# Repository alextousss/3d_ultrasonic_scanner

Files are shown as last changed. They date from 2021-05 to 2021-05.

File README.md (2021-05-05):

pic of a room 3d scanned with ultrasounds
### An Ultrasonic 3D Scanner

Detailed build log and infos [on my website](http://alextoussaint.com/2021-04-28_How-I-built-an-ultrasonic-3d-scanner.html) 

If you're looking for instructions detailed enough to build it for yourself, just add an Issue and I'll do it.
I also haven't had the time to make the code human-readable. Though, it's still understandable.

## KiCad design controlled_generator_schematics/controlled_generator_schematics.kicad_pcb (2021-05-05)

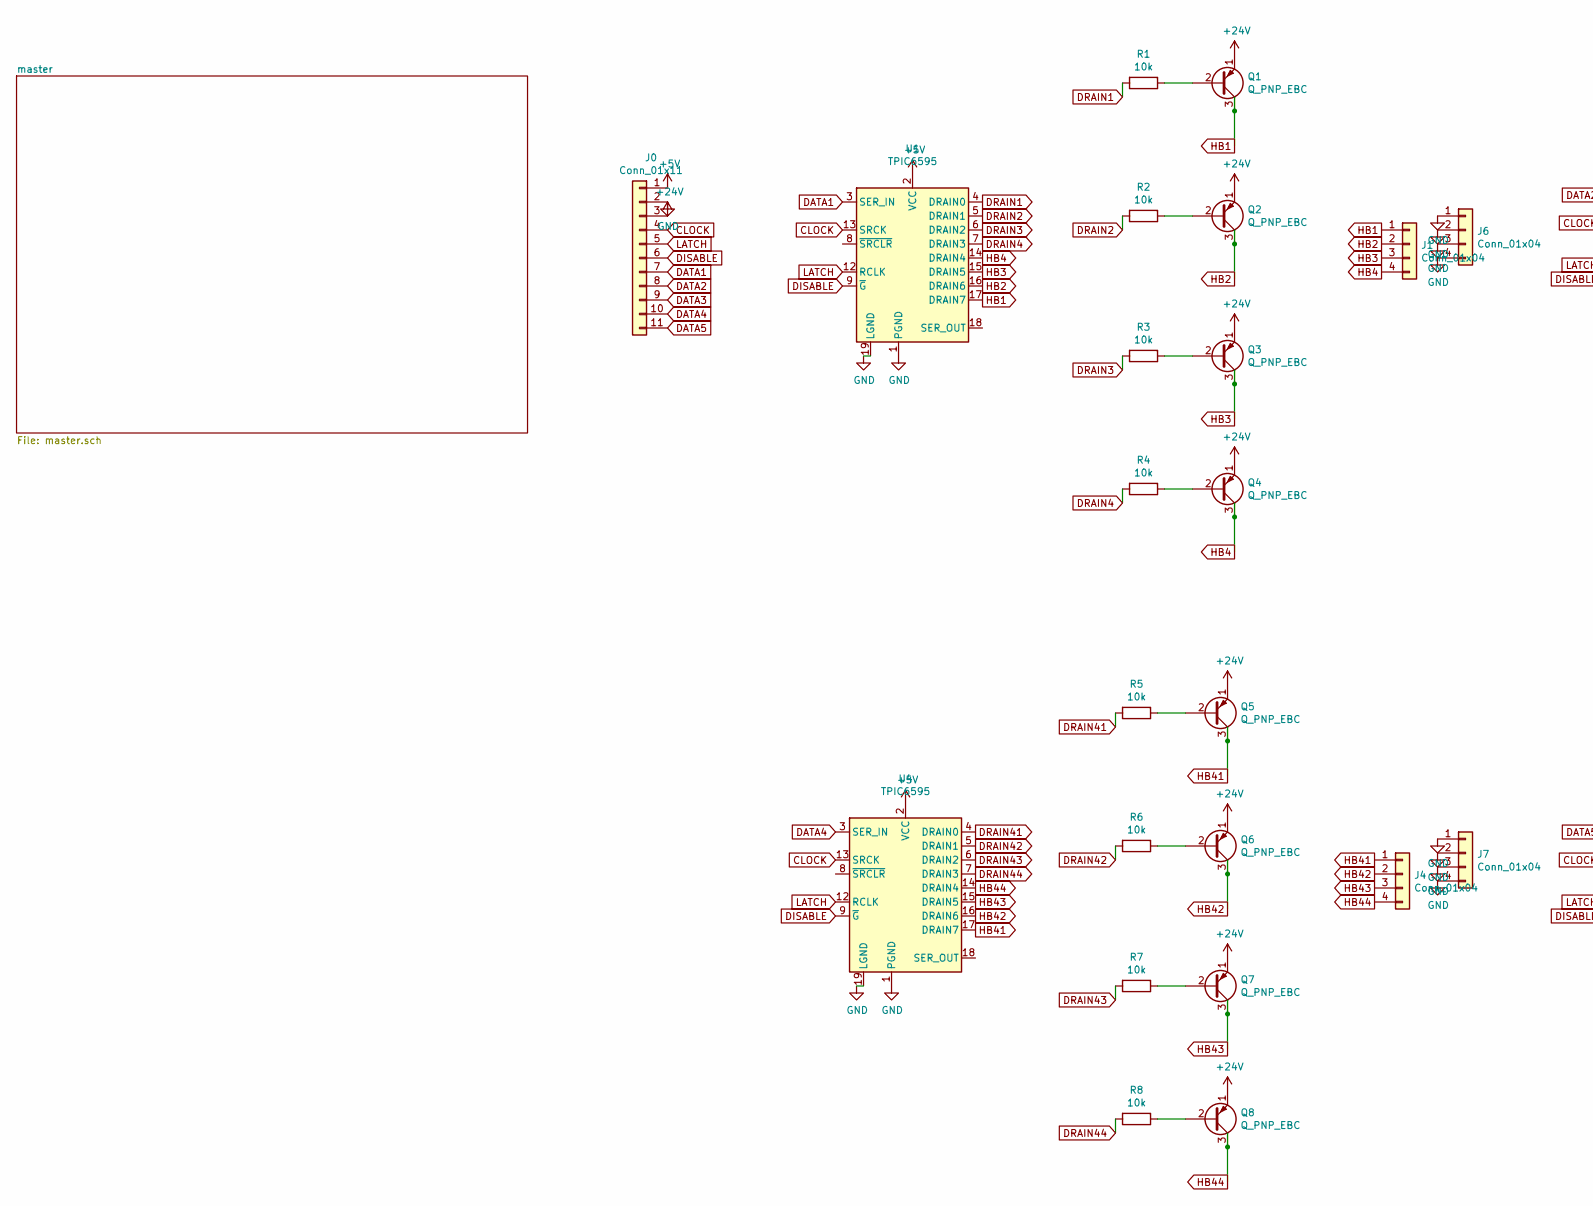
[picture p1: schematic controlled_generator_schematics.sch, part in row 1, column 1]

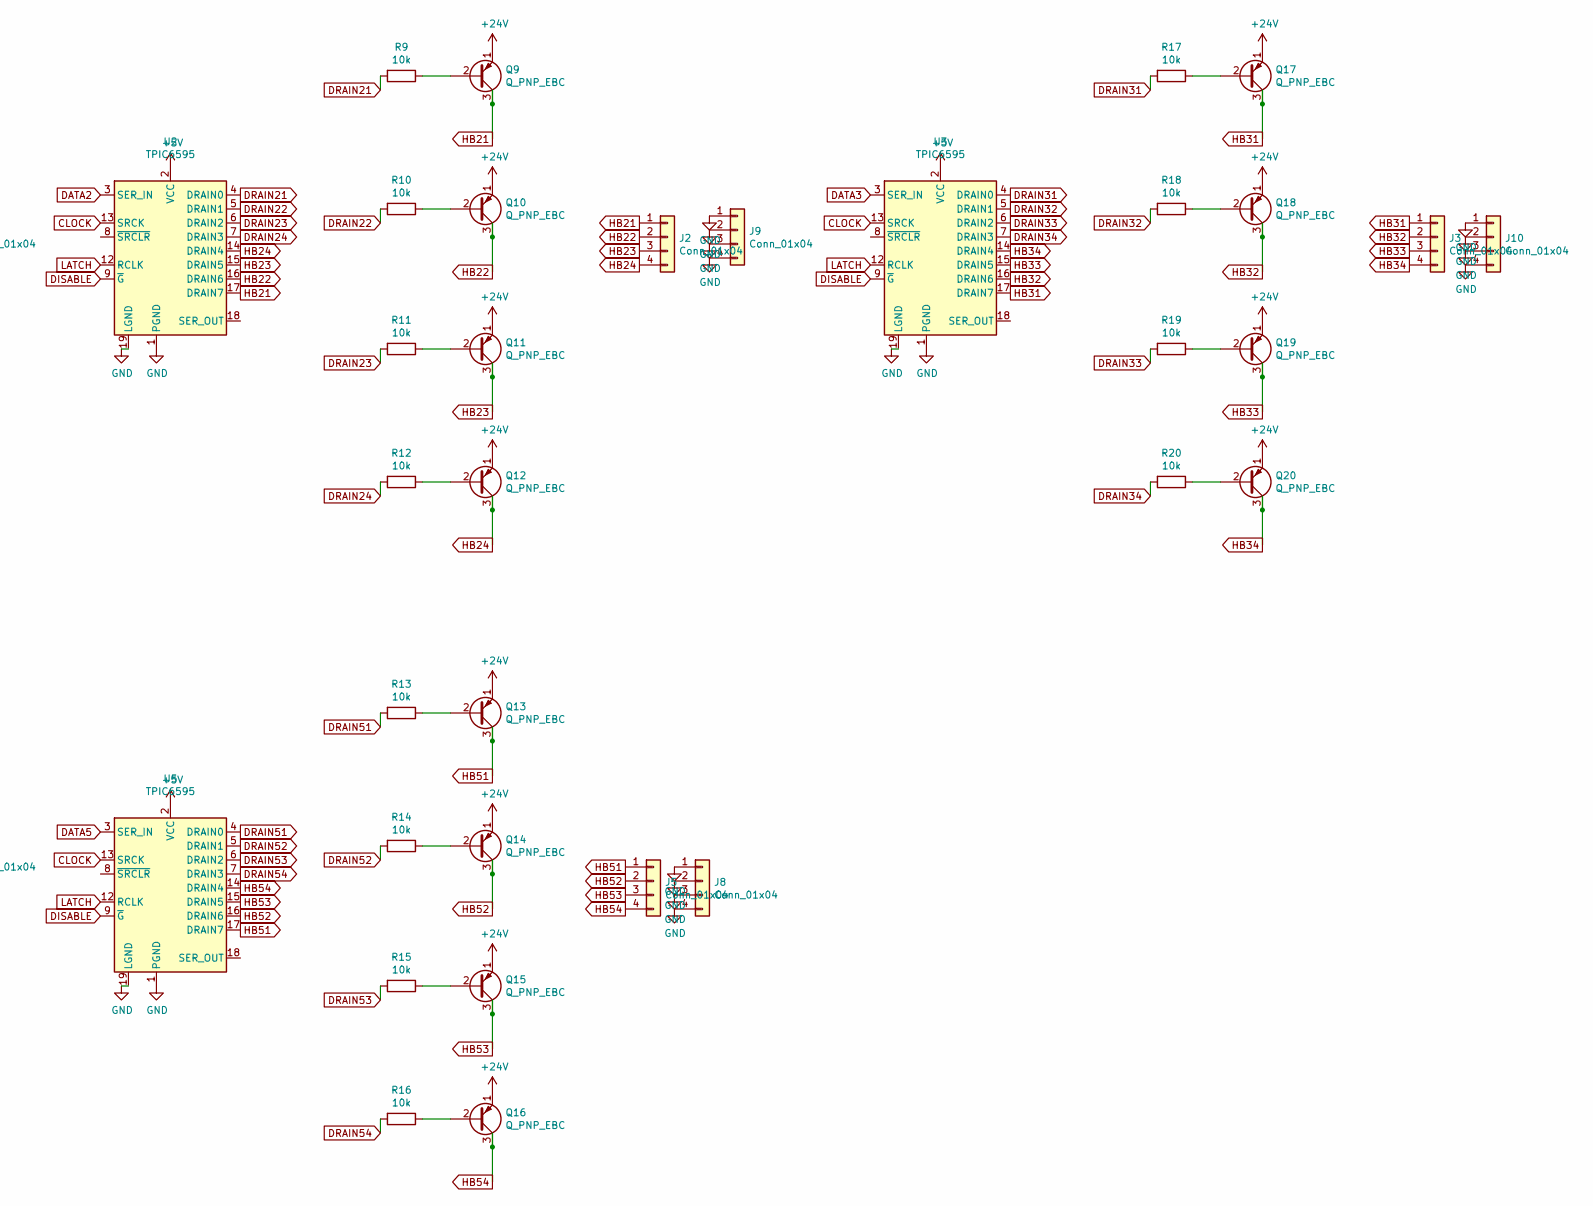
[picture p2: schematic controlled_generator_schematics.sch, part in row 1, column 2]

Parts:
J0: Conn_01x11; PinHeader_1x11_P2.54mm_Horizontal
J1, J2, J3, J4, J5, J6, J7, J8, J9, J10: Conn_01x04; PinHeader_1x04_P2.54mm_Vertical
Q1, Q2, Q3, Q4, Q5, Q6, Q7, Q8, Q9, Q10, Q11, Q12, Q13, Q14, Q15, Q16, Q17, Q18, Q19, Q20: Q_PNP_EBC; TO-92
R1, R2, R3, R4, R5, R6, R7, R8, R9, R10, R11, R12, R13, R14, R15, R16, R17, R18, R19, R20: 10k; R_Axial_DIN0204_L3.6mm_D1.6mm_P2.54mm_Vertical
U1, U2, U3, U4, U5: TPIC6595; DIP-20_W7.62mm_Socket

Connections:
+5V: J0.1, U1.2 (VCC), U2.2 (VCC), U3.2 (VCC), U4.2 (VCC), U5.2 (VCC)
+24V: J0.3, Q1.1 (E), Q2.1 (E), Q3.1 (E), Q4.1 (E), Q5.1 (E), Q6.1 (E), Q7.1 (E), Q8.1 (E), Q9.1 (E), Q10.1 (E), Q11.1 (E), Q12.1 (E), Q13.1 (E), Q14.1 (E), Q15.1 (E), Q16.1 (E), Q17.1 (E), Q18.1 (E), Q19.1 (E), Q20.1 (E)
CLOCK: J0.4, U1.13 (SRCK), U2.13 (SRCK), U3.13 (SRCK), U4.13 (SRCK), U5.13 (SRCK)
DATA1: J0.7, U1.3 (SER_IN)
DATA2: J0.8, U2.3 (SER_IN)
DATA3: J0.9, U3.3 (SER_IN)
DATA4: J0.10, U4.3 (SER_IN)
DATA5: J0.11, U5.3 (SER_IN)
DISABLE: J0.6, U1.9 (~G), U2.9 (~G), U3.9 (~G), U4.9 (~G), U5.9 (~G)
DRAIN1: R1.2, U1.4 (DRAIN0)
DRAIN2: R2.2, U1.5 (DRAIN1)
DRAIN3: R3.2, U1.6 (DRAIN2)
DRAIN4: R4.2, U1.7 (DRAIN3)
DRAIN21: R9.2, U2.4 (DRAIN0)
DRAIN22: R10.2, U2.5 (DRAIN1)
DRAIN23: R11.2, U2.6 (DRAIN2)
DRAIN24: R12.2, U2.7 (DRAIN3)
DRAIN31: R17.2, U3.4 (DRAIN0)
DRAIN32: R18.2, U3.5 (DRAIN1)
DRAIN33: R19.2, U3.6 (DRAIN2)
DRAIN34: R20.2, U3.7 (DRAIN3)
DRAIN41: R5.2, U4.4 (DRAIN0)
DRAIN42: R6.2, U4.5 (DRAIN1)
DRAIN43: R7.2, U4.6 (DRAIN2)
DRAIN44: R8.2, U4.7 (DRAIN3)
DRAIN51: R13.2, U5.4 (DRAIN0)
DRAIN52: R14.2, U5.5 (DRAIN1)
DRAIN53: R15.2, U5.6 (DRAIN2)
DRAIN54: R16.2, U5.7 (DRAIN3)
GND: J0.2, J6.1, J6.2, J6.3, J6.4, J7.1, J7.2, J7.3, J7.4, J8.1, J8.2, J8.3, J8.4, J9.1, J9.2, J9.3, J9.4, J10.1, J10.2, J10.3, J10.4, U1.1 (PGND), U1.10 (PGND), U1.11 (PGND), U1.19 (LGND), U1.20 (PGND), U2.1 (PGND), U2.10 (PGND), U2.11 (PGND), U2.19 (LGND), U2.20 (PGND), U3.1 (PGND), U3.10 (PGND), U3.11 (PGND), U3.19 (LGND), U3.20 (PGND), U4.1 (PGND), U4.10 (PGND), U4.11 (PGND), U4.19 (LGND), U4.20 (PGND), U5.1 (PGND), U5.10 (PGND), U5.11 (PGND), U5.19 (LGND), U5.20 (PGND)
HB1: J1.1, Q1.3 (C), U1.17 (DRAIN7)
HB2: J1.2, Q2.3 (C), U1.16 (DRAIN6)
HB3: J1.3, Q3.3 (C), U1.15 (DRAIN5)
HB4: J1.4, Q4.3 (C), U1.14 (DRAIN4)
HB21: J2.1, Q9.3 (C), U2.17 (DRAIN7)
HB22: J2.2, Q10.3 (C), U2.16 (DRAIN6)
HB23: J2.3, Q11.3 (C), U2.15 (DRAIN5)
HB24: J2.4, Q12.3 (C), U2.14 (DRAIN4)
HB31: J3.1, Q17.3 (C), U3.17 (DRAIN7)
HB32: J3.2, Q18.3 (C), U3.16 (DRAIN6)
HB33: J3.3, Q19.3 (C), U3.15 (DRAIN5)
HB34: J3.4, Q20.3 (C), U3.14 (DRAIN4)
HB41: J4.1, Q5.3 (C), U4.17 (DRAIN7)
HB42: J4.2, Q6.3 (C), U4.16 (DRAIN6)
HB43: J4.3, Q7.3 (C), U4.15 (DRAIN5)
HB44: J4.4, Q8.3 (C), U4.14 (DRAIN4)
HB51: J5.1, Q13.3 (C), U5.17 (DRAIN7)
HB52: J5.2, Q14.3 (C), U5.16 (DRAIN6)
HB53: J5.3, Q15.3 (C), U5.15 (DRAIN5)
HB54: J5.4, Q16.3 (C), U5.14 (DRAIN4)
LATCH: J0.5, U1.12 (RCLK), U2.12 (RCLK), U3.12 (RCLK), U4.12 (RCLK), U5.12 (RCLK)
unnamed: Q1.2 (B), R1.1
unnamed: Q2.2 (B), R2.1
unnamed: Q3.2 (B), R3.1
unnamed: Q4.2 (B), R4.1
unnamed: Q5.2 (B), R5.1
unnamed: Q6.2 (B), R6.1
unnamed: Q7.2 (B), R7.1
unnamed: Q8.2 (B), R8.1
unnamed: Q9.2 (B), R9.1
unnamed: Q10.2 (B), R10.1
unnamed: Q11.2 (B), R11.1
unnamed: Q12.2 (B), R12.1
unnamed: Q13.2 (B), R13.1
unnamed: Q14.2 (B), R14.1
unnamed: Q15.2 (B), R15.1
unnamed: Q16.2 (B), R16.1
unnamed: Q17.2 (B), R17.1
unnamed: Q18.2 (B), R18.1
unnamed: Q19.2 (B), R19.1
unnamed: Q20.2 (B), R20.1

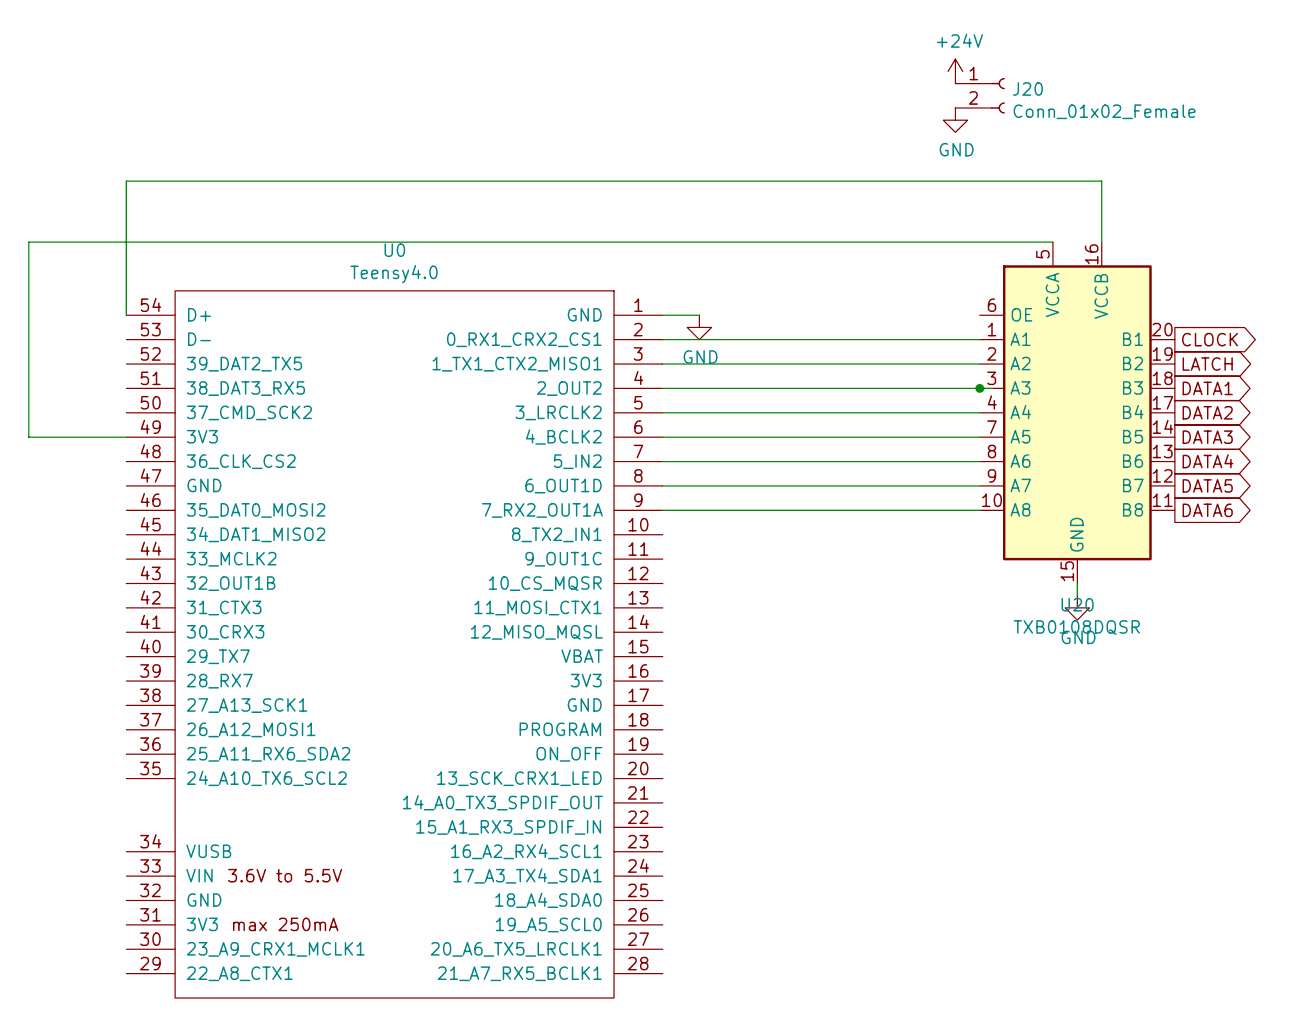
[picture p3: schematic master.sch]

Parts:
J20: Conn_01x02_Female; PinSocket_1x02_P2.54mm_Vertical
U0: Teensy4.0; Teensy40
U20: TXB0108DQSR; TXS0108E

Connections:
unnamed: J20.2, U0.1 (GND), U20.15 (GND)
unnamed: U0.2 (0_RX1_CRX2_CS1), U20.1 (A1)
unnamed: U0.3 (1_TX1_CTX2_MISO1), U20.2 (A2)
unnamed: U0.4 (2_OUT2), U20.3 (A3)
unnamed: U0.5 (3_LRCLK2), U20.4 (A4)
unnamed: U0.6 (4_BCLK2), U20.7 (A5)
unnamed: U0.7 (5_IN2), U20.8 (A6)
unnamed: U0.8 (6_OUT1D), U20.9 (A7)
unnamed: U0.9 (7_RX2_OUT1A), U20.10 (A8)
unnamed: U0.49 (3V3), U20.5 (VCCA)
unnamed: U0.54 (D+), U20.16 (VCCB)

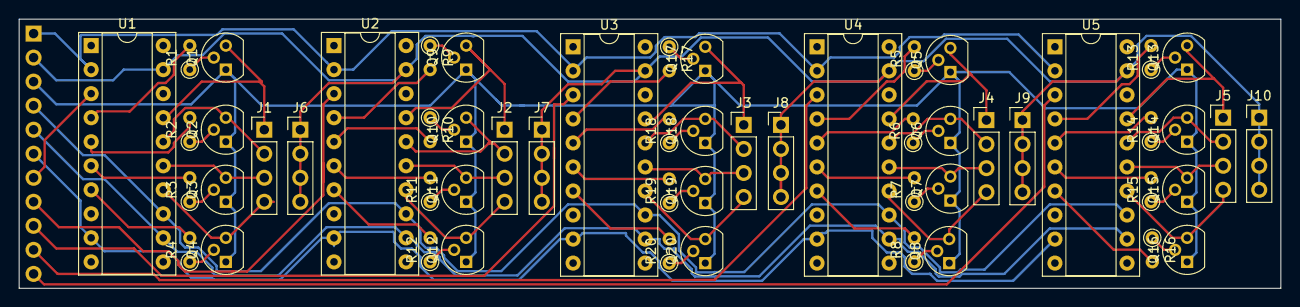
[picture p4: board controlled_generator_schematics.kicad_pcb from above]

Board: 2 copper layers, 133.4 x 28.4 mm, 56 parts (1 on the bottom side), 71 nets.

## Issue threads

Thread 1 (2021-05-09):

Another possibility why this application didn't exist yet

JobLeonard, 2021-05-09:
First of all, amazing work and great write-up too! In case you weren't aware, [someone linked the article on Hacker News](https://news.ycombinator.com/item?id=27090795)

Anyway, you mentioned that you were trying to figure out why this (apparently) wasn't done before and being open to other suggestions. Well, 3D ultrasounds are a thing, but they're used for a very different purpose, namely medical imaging:

https://en.wikipedia.org/wiki/3D_ultrasound

https://www.ncbi.nlm.nih.gov/pmc/articles/PMC5385255/

https://www.ob-ultrasound.net/brown3d.html

http://www.engineeringhalloffame.org/profile-brown.html

http://ardms.org/get-certified/Pages/SPI.aspx

Apparently Tom Brown, one of the pioneers of ultrasound imaging, already made strides into 3D ultrasound imaging in 1975!

This is the first thing I found when searching for "3D ultrasound" (on DuckDuckGo) so I'm kind of wondering how this slipped through. It's not quite the same application but it still counts, no?

Anyway, I'm not saying this to discourage you - if anything it hopefully gives some ideas for refining your approach, no?

Keep up the good work!

(also, off-topic, but please consider adding an RSS feed to your blog so I can subscribe to it)

JobLeonard, 2021-05-09:
(also, the title changed because I basically discovered all of this while writing the issue - at first I was going to suggest that this wasn't done before because medical and geological ultrasound were very different applications, then I decided to double check my own hypothesis)

alextousss, 2021-05-09:
The title of the Hacker News link is a bit misleading. In my article, I wrote that this was the first (of my knowledge) ultrasonic 3d scanner *that works in the air*.

Ultrasound imaging in the air is different than in physical materials because waves travel in different ways. Especially, one of the hardest challenge was building a scanner with transducers wider than the wavelength of the signal. In the water or in human bodies, the wavelength of ultrasonic waves is much larger than in the air. That simplifies the design.

Though, thank you for the links and the discussion!

I built my own blog engine in python (really just an 80-lines python script) so I'll have to build RSS myself. But, I can do it.

alextousss, 2021-06-04:
Here it is ;-) https://www.alextoussaint.com/feed.xml

JobLeonard, 2021-06-05:
Great! Needs a minor fix though. The RSS feed sends me to:

https://www.alextoussaint.com/posts/2021-04-28_How-I-built-an-ultrasonic-3d-scanner.md

That gives me a 404. The actual page is:

https://www.alextoussaint.com/2021-04-28_How-I-built-an-ultrasonic-3d-scanner.html

I guess it confuses the source markdown file for the output?

alextousss, 2021-06-05:
Exactly! Plus I've added the "/posts/" which isn't necessary.
Thanks for the catch! Should have checked myself ...
Will change that as soon as I have time.

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

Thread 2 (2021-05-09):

Wider FOV with motorized mount?

jzellis, 2021-05-09:
Hi! First of all, this is amazing, well done!

You mentioned in your blog that it's limited to about a 45° FOV in two axes. Could you mount it on a stepper motor to rotate the transducers in one or both axes and then "stitch" your captured plots together, in the way that a phone camera stitches panoramic shots? It might not be useful in an environment with moving objects - or if the scanner is moving itself - but it would probably provide a cheap and easy way to extend the capabilities without necessarily building more arrays.

(The motor itself might produce noise, of course, but that could probably be compensated for.)

Dunno, just a thought. But keep up the good work! If you get to the point of producing a kit or commercial product, I'd love to get one and try it out!

alextousss, 2021-05-09:
Yes, you could mount it on steppers to have a 360° FOV.  Unless the stepper's hashing frequency is close to 40khz, the motor wouldn't interfere at all with the scanner!

I don't think I'll sell a kit until next year. In the meantime, I can definitely build a few  units of my current design. It takes me quite some time to build one though. If it isn't too rude to ask: how much would you pay to get an unit?

Thank you for the compliments!

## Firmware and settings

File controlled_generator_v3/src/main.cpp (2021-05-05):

#include <Arduino.h>
#include "PinInfo.h"

int latchPin = 1;
int clockPin = 0;
int angle_x=0;
int angle_y=0;
int active_emitter = 0;


void prnt8Bits(byte b) {
    for(int i = 7; i >= 0; i--)
        Serial.print(bitRead(b,i));
}
void prntBits(uint32_t b) {
    for(int i = 31; i >= 0; i--)
        Serial.print(bitRead(b,i));
}



uint8_t null_data[]= {
    B00000000,
    B00000000,
    B00000000,
    B00000000,
    B00000000,
    B00000000,
    B00000000,
    B00000000,
    B00000000,
    B00000000,
    B00000000,
    B00000000,
    B00000000,
    B00000000,
    B00000000,
    B00000000,
    B00000000,
    B00000000,
    B00000000,
    B00000000,
};


int portPerPin[] = {
    6,6,9,9,9,9,7,7,7,7,7,7,7,7,6,6,6,6,6,6,6,6,6,6,6,6,6,6,8,9,8,8,7,9,8,8,8,8,8,8
};

uint32_t pinmaskPerPin[] = {
    0x8, 0x4, 0x10, 0x20, 0x40, 0x100, 0x400, 0x20000, 0x10000, 0x800, 0x1, 0x4, 0x2, 0x8, 0x40000, 0x80000, 0x800000, 0x400000, 0x20000, 0x10000, 0x4000000, 0x8000000, 0x1000000, 0x2000000, 0x1000, 0x2000, 0x40000000, 0x80000000, 0x40000, 0x80000000, 0x800000, 0x400000, 0x1000, 0x80, 0x8000, 0x4000, 0x2000, 0x1000, 0x20000, 0x10000
};




void generatePort(int len, int dataPins[], uint8_t data[], uint32_t out[][3], int *outLen) {
    unsigned int i = 0;
    // latchPin: low
    out[i][0] = 0; 
    out[i][1] = 0; 
    out[i++][2] = 0; 
    for(unsigned int j = 0; j < 8; j++) {
        out[i+j*3][0] = out[i+j*3-1][0];
        out[i+j*3][1] = out[i+j*3-1][1];
        out[i+j*3][2] = out[i+j*3-1][2];
        for(unsigned int k = 0; k < len; k++) {
            bool bit = !!(data[k] & (1 << j));
            int place = 0;
            int port = portPerPin[dataPins[k]];
            //           Serial.print("time to PinInfo="); Serial.println(micros()-start_ts_2);
            unsigned long start_ts_1 = micros();
            if(port == 6) place = 0;
            if(port == 7) place = 1;
            if(port == 9) place = 2;
            uint32_t pinmask = pinmaskPerPin[dataPins[k]];
            //prntBits(pinmask);
            if (bit) {
                out[i+j*3][place] = out[i+j*3][place] | pinmask;
            } else {
                out[i+j*3][place] = out[i+j*3][place] & ~pinmask;
            }
            //            Serial.print("time to write="); Serial.println(micros()-start_ts_1);
            // Serial.print("time in looop="); Serial.println(micros()-start_ts_0);
            //out[i+j*3][0] &= ~digitalPinToBitMask(clockPin); // wtf was that anyway?
        }
        out[i+j*3+1][0] = out[i+j*3][0] | CORE_PIN0_BITMASK;
        out[i+j*3+2][0] = out[i+j*3][0] & ~CORE_PIN0_BITMASK;
        out[i+j*3+1][1] = out[i+j*3][1]; // Ofc we're keeping the data! Only the clock bit should change
        out[i+j*3+2][1] = out[i+j*3][1];
        out[i+j*3+1][2] = out[i+j*3][2];
        out[i+j*3+2][2] = out[i+j*3][2];
    }
    // three values for each iteration of j (1 data, 1 clock low, 1 clock high) and -1 bcoz it works better this way
    i = i+8*3-1;
    // latchPin: high
    out[i+1][0] = (out[i][0] | CORE_PIN1_BITMASK); // On mets la latch à zéro
    // +2 car +1 pour la ligne d'avant et +1 pour car un tableau de taille n a un indice de fin n-1
    *outLen = i+2;
}


void setup () {
    Serial.begin(9600);
    for(unsigned int i = 0; i < 28; i++) {
        pinMode(i, OUTPUT);
    }
}


#define BUF_SIZE (29952/5) // (26*60)
//#define DEBUG
void optimiser(uint32_t data[][3], int len) {
    //while(Serial.available() <= 0){ 
    for(int j = 0; j < 1; j++) 
        for(unsigned int i = 0; i < len; i++) {
#ifdef DEBUG
            delay(1);
            prntBits(data[i][0]); Serial.print("\t");
            prntBits(data[i][1]); Serial.print("\t");
            prntBits(data[i][2]); Serial.print("\n");
            //    Serial.println(data[i], BIN);
#endif
            delayNanoseconds(1);
            GPIO6_DR = data[i][0];
            GPIO7_DR = data[i][1];
            GPIO9_DR = data[i][2];
        }

    //   delay(50);

    //    }
}

int portOfEmitter[] = {
    0, 1, 2, 3, 4, 5, 6, 7, 10, 11, 
    12, 13, 14, 15, 16, 17, 18, 19, 8, 9,
    20, 21, 22, 23, 36, 37, 38, 39, 34, 35,
    24, 25, 26, 27, 28, 29, 30, 31, 32, 33,    
    40, 41, 42, 43, 44, 45, 46, 47, 48, 49,    
    56, 57, 58, 59, 52, 53, 54, 55, 50, 51,    
    60, 61, 62, 63, 64, 65, 66, 67, 68, 69,    
    76, 77, 78, 79, 72, 73, 74, 75, 70, 71,    
};

typedef enum {OFF, MINUS, MINUS_TO_PLUS, PLUS, PLUS_TO_MINUS} state_t;

typedef struct {
    unsigned int id;
    unsigned int start_inc; // increment at which the wave starts
    unsigned int waiting_for; // number of increments during on/off switch delay
} Emitter;

int getPort(Emitter em) {
    return portOfEmitter[em.id]; 
}

uint8_t getPinMask(int pin) {
    uint8_t pin_mask = B00000000;
    if(pin%4 == 0)
        pin_mask = B10000001;
    if(pin%4 == 1)
        pin_mask = B01000010;
    if(pin%4 == 2)
        pin_mask = B00100100;
    if(pin%4 == 3)
        pin_mask = B00011000;
    return pin_mask;
}





uint32_t data[BUF_SIZE][3];

void loop() {
    if(Serial.available() > 0) {
        Serial.println("portPerPin = {");
        //Serial.println(Serial.read());
        int read= Serial.read();
        if(read == 104) { // "h"
            for(unsigned int i = 0; i < 40; i++) {
                int port = PinInfo(i).gpioInfo.gpioPortNr;
                Serial.print(port); Serial.print(",");
            }
            Serial.println("}");

            Serial.println("pinmaskPerPin = {");
            for(unsigned int i = 0; i < 40; i++) {
                uint32_t pinmask = (1<<PinInfo(i).gpioInfo.gpioBitNr);
                Serial.print("0x"); Serial.print(pinmask, HEX); Serial.print(", ");
            }
            Serial.println("}");
        }

        bool active = read == 97; // If it's a "a"!
        if(read == 114) {
            angle_x = -21;
        }
        if(read == 116) {
            angle_y = -21;
        }
        if(read == 121) {
            angle_y = 0;
        }

        if(read == 122) {
            angle_x++;
        }
        if(read == 115) {
            angle_x--;
        }

        if(read == 101) {
            angle_y++;
        }
        if(read == 100) {
            angle_y--;
        }
        if(read == 112) {
            active_emitter++;
        }
        if(read == 111) {
            active_emitter--;
        }


        // angle_x++;
        if(angle_x == 22) {
            angle_x = -21;
        }
        if(angle_y == 22) {
            angle_y = -21;
        }
        if(active) {
            //delay(100); 
            //Serial.println("----------------------------");
            for(int i = 0; i < BUF_SIZE; i++) {
                data[i][0] = 0;
                data[i][1] = 0;
                data[i][2] = 0;
            }
            Emitter emitters[80];
            for(unsigned int i = 0; i < 80; i++) {
                unsigned int start_inc = (i%10)*angle_x + (i/10)*angle_y; 
                emitters[i] = {
                    .id = i,
                    .start_inc = start_inc,
                    .waiting_for=0,
                };
            }

            unsigned int index = 0; 
            unsigned int period=2;

            //Serial.print("Register ID: "); Serial.println(register_id);
            uint8_t active_data[] = {
                B00000000,
                B00000000,
                B00000000,
                B00000000,
                B00000000,
                B00000000,
                B00000000,
                B00000000,
                B00000000,
                B00000000,
                B00000000,
                B00000000,
                B00000000,
                B00000000,
                B00000000,
                B00000000,
                B00000000,
                B00000000,
                B00000000,
                B00000000
            };   //Serial.print("Pin Mask: "); prntBits(pin_mask); Serial.println();
#define TOTAL_LENGTH (BUF_SIZE/26-18)

            unsigned long start_ts_0 = millis();
            for(unsigned int i = 0; i < TOTAL_LENGTH; i++) {
                for(int j = 0; j < 80; j++) {
                    //if(j!= active_emitter) continue;
                    Emitter *em = &emitters[j];
                    unsigned int register_id = getPort(*em)/4;
                    uint8_t pin_mask = getPinMask(getPort(*em));
                    int phi = (i-em->start_inc)%42;
                    //     Serial.print(phi); Serial.print("\t");
                    if((phi < 3) || (phi > 21 && phi < 21+3)) {
                        active_data[register_id] = (active_data[register_id] & ~pin_mask) | (B00000000 & pin_mask);
                    } else if(phi < 21) {
                        active_data[register_id] = (active_data[register_id] & ~pin_mask) | (B11110000 & pin_mask);
                    } else if(phi > 21) {
                        active_data[register_id] = (active_data[register_id] & ~pin_mask) | (B00001111 & pin_mask);
                    }
                }
                //Serial.println();
                int outlen = -1;
                int dataPins[] = {2, 3, 4, 5, 6, 7, 8, 9, 10, 11, 12, 13, 14, 15, 16, 17, 18, 19, 20, 21};
                //int dataPins[] = {2, 3, 4, 5, 6, 7, 8, 9, 10, 11};
                if(i == TOTAL_LENGTH-1) {
                    generatePort(20, dataPins, null_data, data + index, &outlen); 
                } else {
                    generatePort(20, dataPins, active ? active_data: null_data, data + index, &outlen); 
                }
                //Serial.print(index); 
                //for(unsigned int o = 0; o < 20; o++) {
                //Serial.print("\t"); prnt8Bits(active_data[o]);
                //} 
                //Serial.println();
                index += outlen;

            }
            Serial.print("total time="); Serial.println(millis()-start_ts_0);
            Serial.print("active_emitter:"); Serial.print(active_emitter); Serial.print("angle_x:"); Serial.print(angle_x); Serial.print("angle_y:"); Serial.println(angle_y);
            //    digitalWriteFast(LED_BUILTIN, HIGH);
            optimiser(data, index); //{
            //   digitalWriteFast(LED_BUILTIN, LOW);
        }
        }
    }

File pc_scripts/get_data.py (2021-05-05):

from tqdm import tqdm
from time import sleep
import os.path
import struct
import time
import json
import math
import serial
import serial.tools.list_ports
import matplotlib
import matplotlib.pyplot as plt
import numpy as np
from scipy.signal import butter, lfilter, hilbert
from mpl_toolkits.mplot3d import Axes3D

BUF_SIZE = 5000


def butter_bandpass(lowcut, highcut, fs, order=5):
    nyq = 0.5 * fs
    low = lowcut / nyq
    high = highcut / nyq
    b, a = butter(order, [low, high], btype="band")
    return b, a


def butter_bandpass_filter(data, lowcut, highcut, fs, order=1):
    b, a = butter_bandpass(lowcut, highcut, fs, order=order)
    y = lfilter(b, a, data)
    return y


def t(i):
    return ((float(i) / fs)) * 340 / 2


fs = 138888
lowcut = 38000
highcut = 42000


startMarker = 254
endMarker = 255


ports = list(serial.tools.list_ports.comports())
port_emitter = ""
port_receiver = ""
for p in ports:
    print(p.hwid)
    if "SER=8033700" in p.hwid:
        port_emitter = p[0]
    if "SER=1819010" in p.hwid:
        port_receiver = p[0]

print("emitter=", port_emitter, "\treceiver=", port_receiver)
ser_emitter = serial.Serial(port_emitter, 9600)
ser_receiver = serial.Serial(port_receiver, 4608000, timeout=10)
sleep(0.1)
ser_emitter.setRTS(False)
ser_receiver.setRTS(False)
sleep(0.1)
ser_receiver.setRTS(True)
ser_emitter.setRTS(True)


datas = []
for x in tqdm(range(42)):
    for i in range(42):
        ts_start = time.time()
        emitter_str = "z"
        if i == 0:
            emitter_str = "re"
        if x == 0 and i == 0:
            emitter_str += "t"
        emitter_str += "a"
        ser_receiver.write(
            str(
                "a"
                # chr(startMarker) + chr(len("hey")) + "hey" + chr(endMarker)
            ).encode()
        )
        # print("written to receiver!")

        # print("writing {} to emitter".format(emitter_str))
        # print("writing at ", time.time() - ts_start)
        ser_emitter.write(
            str(
                emitter_str
                # chr(startMarker) + chr(len("O")) + "O" + chr(endMarker)
            ).encode()
        )
        # for _ in range(len(emitter_str)):
        #     print("emitter sent", ser_emitter.readline())
        data = ser_receiver.read(BUF_SIZE * 2 * 2)
        if len(data) != BUF_SIZE * 2 * 2:
            print("one invalid frame of size", len(data))
            data2 = ser_receiver.read(BUF_SIZE * 2 * 2)
            print(len(data2), "is the length of the next stored message")
        data = struct.unpack("h" * (len(data) // 2), data)

        points = []
        for j in range(BUF_SIZE):
            points.append([data[2 * j], data[2 * j + 1]])
            """
        data1 = [e[0] for e in points]
        data2 = [e[1] for e in points]
        data1 = butter_bandpass_filter(data1, lowcut, highcut, fs, 2)
        data2 = butter_bandpass_filter(data2, lowcut, highcut, fs, 2)
        data1 = hilbert(np.abs(data1))
        data2 = hilbert(np.abs(data2))
        diff = data1 - data2
        plt.subplot(3, 1, 1)
        plt.plot(data1)
        plt.subplot(3, 1, 2)
        plt.plot(data2)
        plt.subplot(3, 1, 3)
        plt.title("angle: " + str(i))
        plt.plot(diff)
        plt.show()
        """
        if x > 21:
            data = [e[1] for e in points]
        else:
            data = [e[0] for e in points]

        datas.append(data)
        # print("total time", time.time() - ts_start)
# print(datas)
i = 0
while os.path.isfile("data{}.json".format(i)):
    i += 1

with open("data{}.json".format(i), "w") as dump:
    print("saving as data{}.json".format(i))
    dump.write(json.dumps(datas))
